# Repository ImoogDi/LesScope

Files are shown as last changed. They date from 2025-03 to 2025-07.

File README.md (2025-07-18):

# LesScope
Arduino based Dual Channel Scope for eurorack-modular synths.

**Table of Contents**

- [Introduction](#intro)
- [Construction Guide](./doc/constructionguide.md)
- [LesScope-Menu](#menu)
- [Technical data](#technical-data)
- [References](#references)
- [License](#license)

## Introduction

This eurorack-modul is designed for modular-synthesizers as dual channel scope modul.  
Only two active parts are required to sample the signal at the jack-inputs.  
 1. Arduino Nano V3.x.  
 2. Quad Op Amp MCP6004 rail-to-rail input/output.  

The Arduino Nano samples the amplified signal on two 10-Bit A/D multiplexed inputs.  
Sampled-data are then traced on the 1.3'' OLED display.  
Dataentry and menu-selections are possible with that encoder <u>Select</u>.  
AC/DC coupling is selectable for both channels on two switches.  
Every channel has two jacks linked together for signal-input and routing to other inputs.  
That signal on <u>Channel1</u> is normalized to the <u>Trigger</u> input-jack.  
With an additonal cable plugged into the <u>Trigger</u> jack a different trigger-signal can be used.  

All parts are common available and DIY-friendly designed.   
(Details see attached pictures)  

- Modul Frontpanel  
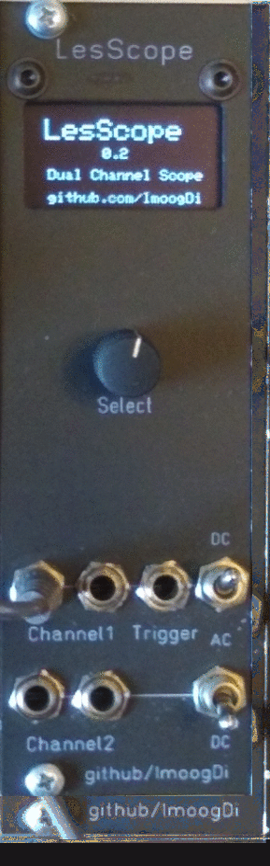
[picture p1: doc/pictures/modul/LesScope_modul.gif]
Modul: LesScope Front
 

- Modul Backside  
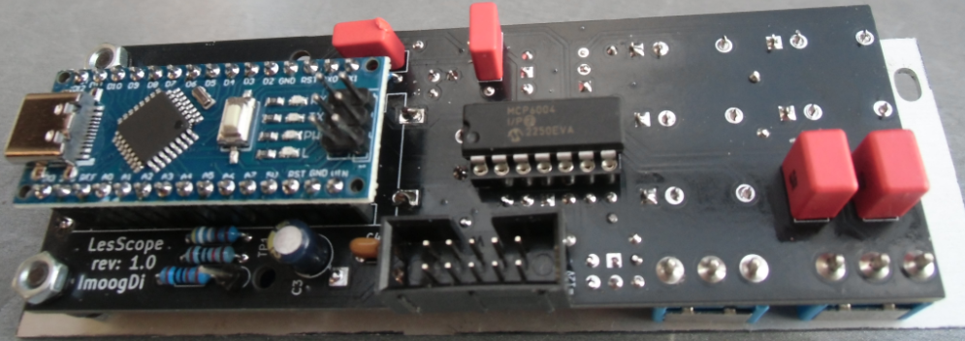
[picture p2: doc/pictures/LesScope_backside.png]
Modul: LesScope Backside
 

- Modul Right side  
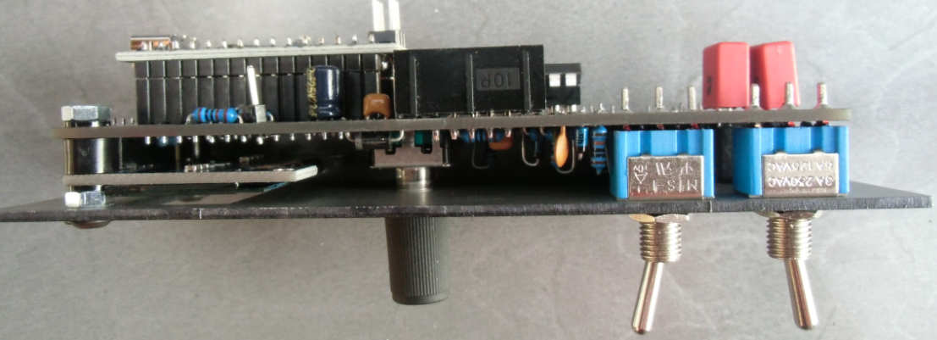
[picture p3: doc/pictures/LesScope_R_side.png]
Modul: LesScope Backside
 

- Modul Left side  
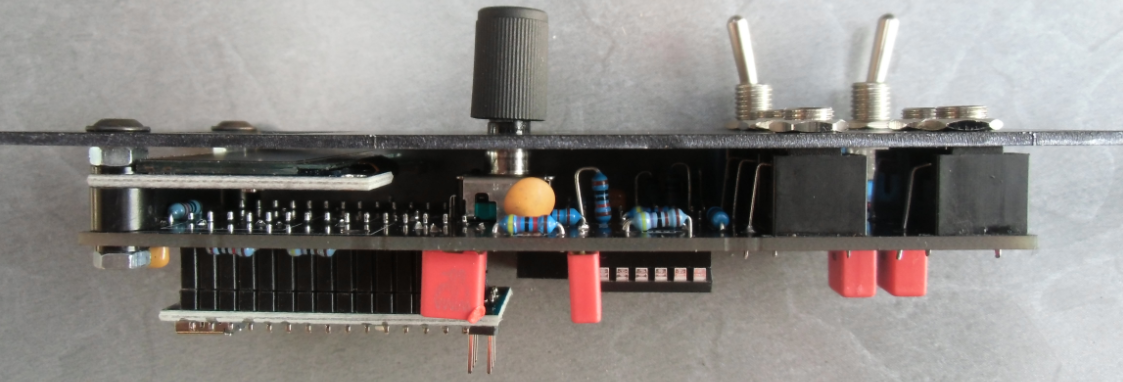
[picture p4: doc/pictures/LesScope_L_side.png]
Modul: LesScope Backside
 

- Dual Trace example  
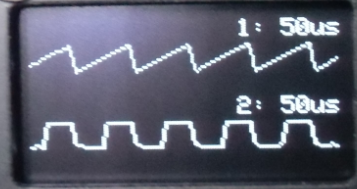
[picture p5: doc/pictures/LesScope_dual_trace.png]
Dual Trace example
 

## LesScope-Menu
- Menu example  
Menu example
 

## Technical data

- size:  
  height: 3VP (133,35mm)  
  width : 8HP ( 40,3mm)  
  depth : 35mm

- power:  
   +5Volt, 0 mA  
  +12Volt, 45mA  
  -12Volt, 0 mA  

- display:  
    128x64 pixel 1.3inch OLED with SPI interface  

- MCU:  
    Arduino Nano V3.x ATmega 328P  

- Electrical features:  
    Rotary encoder with push-button.  
    Two separate channels with AC/DC-coupling.  
    Input Voltage 10Vp-p for both channels.  
    Menu selectable signal-amplification (1...4:Channel1; 1...2:Channel2).  
    Sampling-rate range: 50us...100msec on both channels.  
    Separate trigger-input (default linked to <u>Channel1</u>).  

- Measurement-capabilities (only on <u>Channel1</u>):  
    Frequency-measurement range: ~10Hz...~6000Hz.  
    Tuning-check range: C0(16.35Hz)...C8(4186.01Hz).  

There are fife 3.5mm jacks available with following functions.  
<table>
<tr>
    <th>Jack-Name</th>
    <th>Function</th>
    <th>Comment</th>
</tr>
<tr>
    <td>Channel1 (two jacks)</td>
    <td>Signal input for <u>Channel1</u></td>
    <td>the two jacks are linked together and <br>this signal is normalized to <u>Trigger</u> input.</td>
</tr>
<tr>
    <td>Channel2 (two jacks)</td>
    <td>Signal input for <u>Channel2</u></td>
    <td>the two jacks are linked together.</td>
</tr>
<tr>
    <td>Trigger</td>
    <td>Signal input for <u>Trigger</u></td>
    <td>this signal is normalized to <u>Channel1</u>.</td>
</tr>
</table>

## References

* [mzuelch Display](https://github.com/mzuelch/CATs-Eurosynth/tree/main/Modules/HAGIWO/Display)
* [frequency measure](http://www.pjrc.com/teensy/td_libs_FreqMeasure.html)
* [encoder](http://www.pjrc.com/teensy/td_libs_Encoder.html)
* [Adafruit SH110X display-driver](https://github.com/adafruit/Adafruit_SH110X/actions)
* [midi conversion table](https://musicinformationretrieval.com/midi_conversion_table.html)

## License
> Hardware:cc by-nc-sa 4.0  ([details](https://creativecommons.org/licenses/by-nc-sa/4.0/))  
> Software:licensed under GPL-3.0 ([details](https://www.gnu.org/licenses/gpl-3.0.html.en))

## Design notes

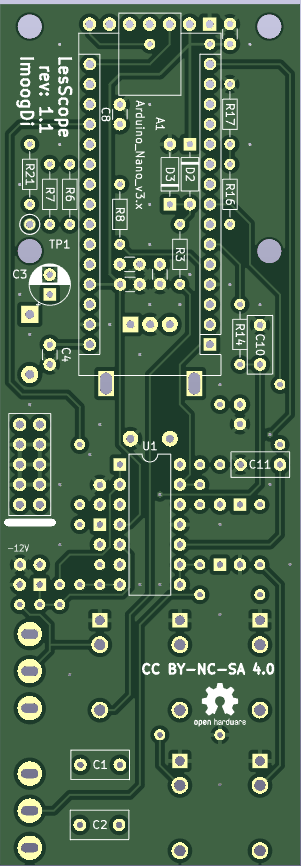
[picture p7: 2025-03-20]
doc/pictures/LesScope_Bot.png

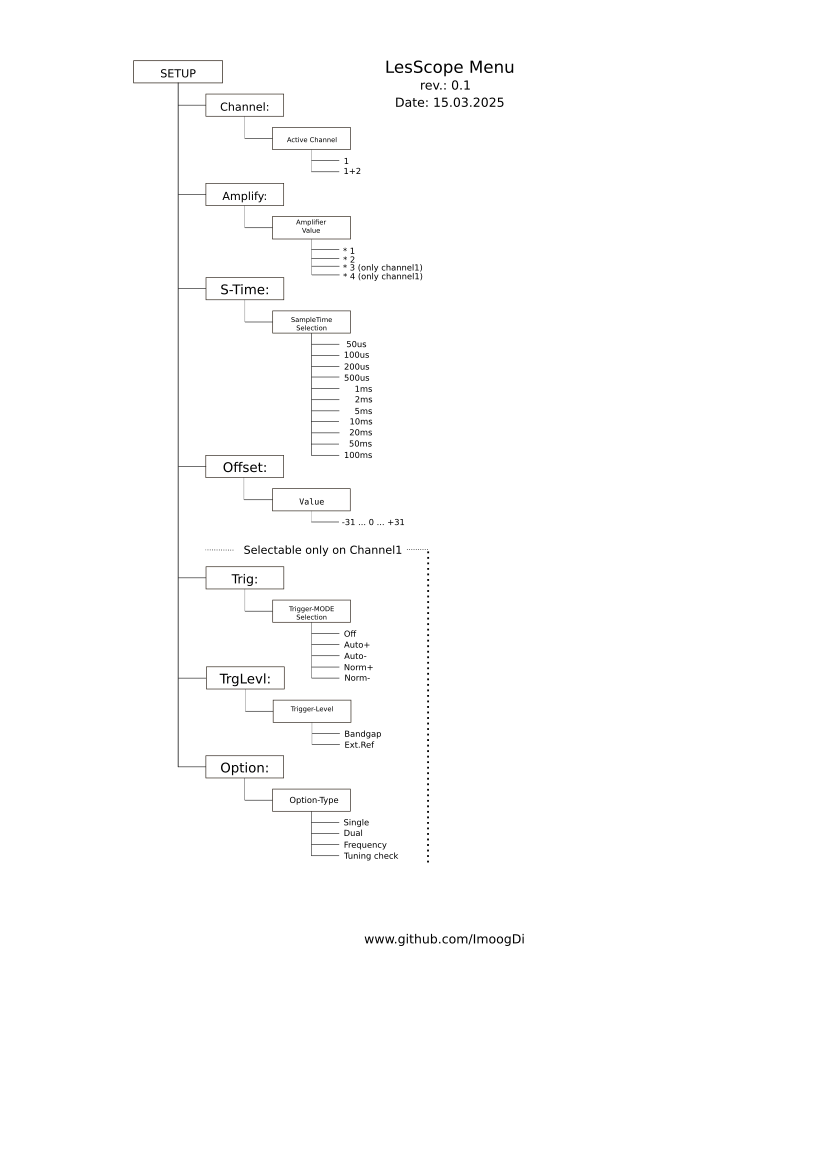
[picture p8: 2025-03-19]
doc/pictures/menu/LesScope_Menu_Struct.png

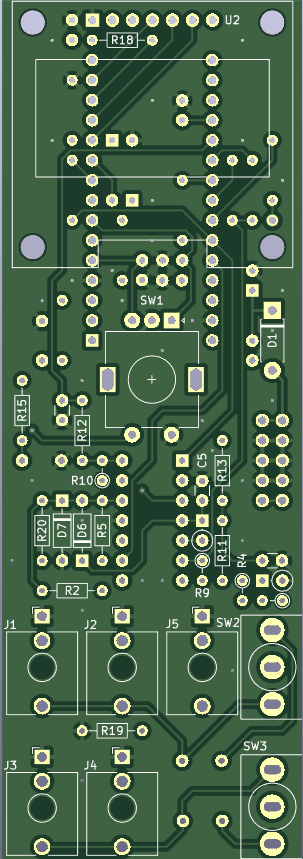
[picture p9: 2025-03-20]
doc/pictures/LesScope_Top.png

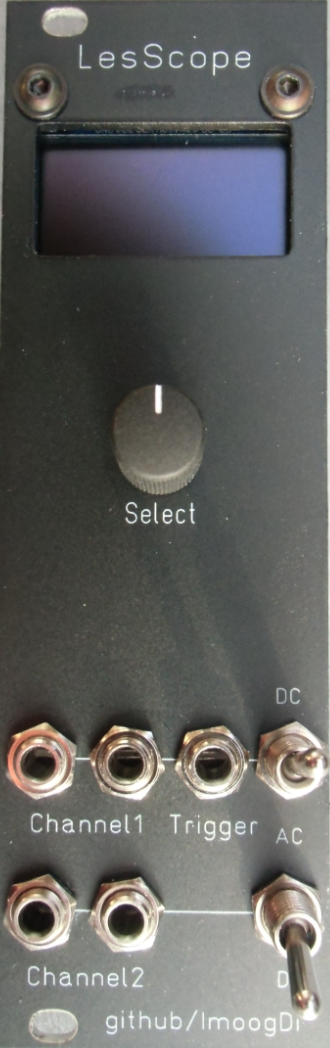
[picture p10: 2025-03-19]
doc/pictures/LesScope_front.png

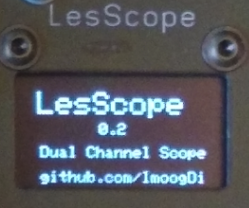
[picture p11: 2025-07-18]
doc/pictures/LesScope_startup.png

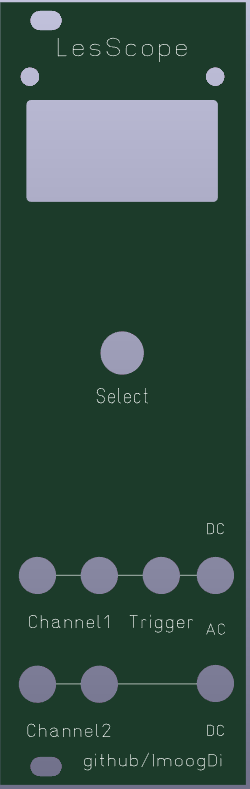
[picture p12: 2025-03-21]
hw/frontpanel/LesScope_frontpanel.png

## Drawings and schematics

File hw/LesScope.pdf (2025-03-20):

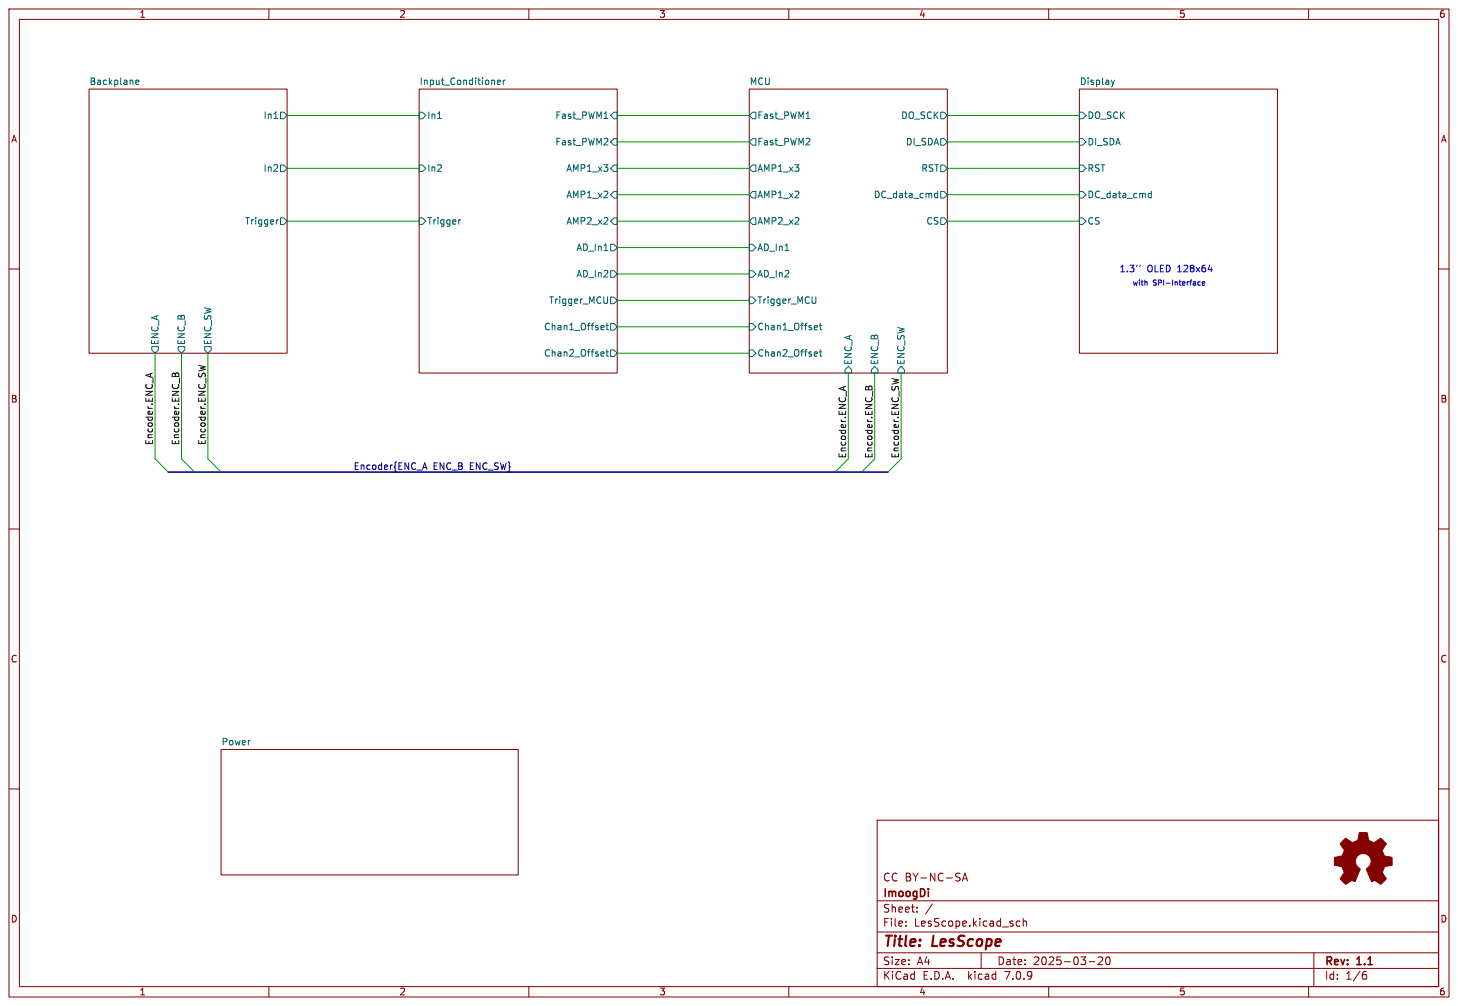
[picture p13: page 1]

ImoogDi CC BY-NC-SA

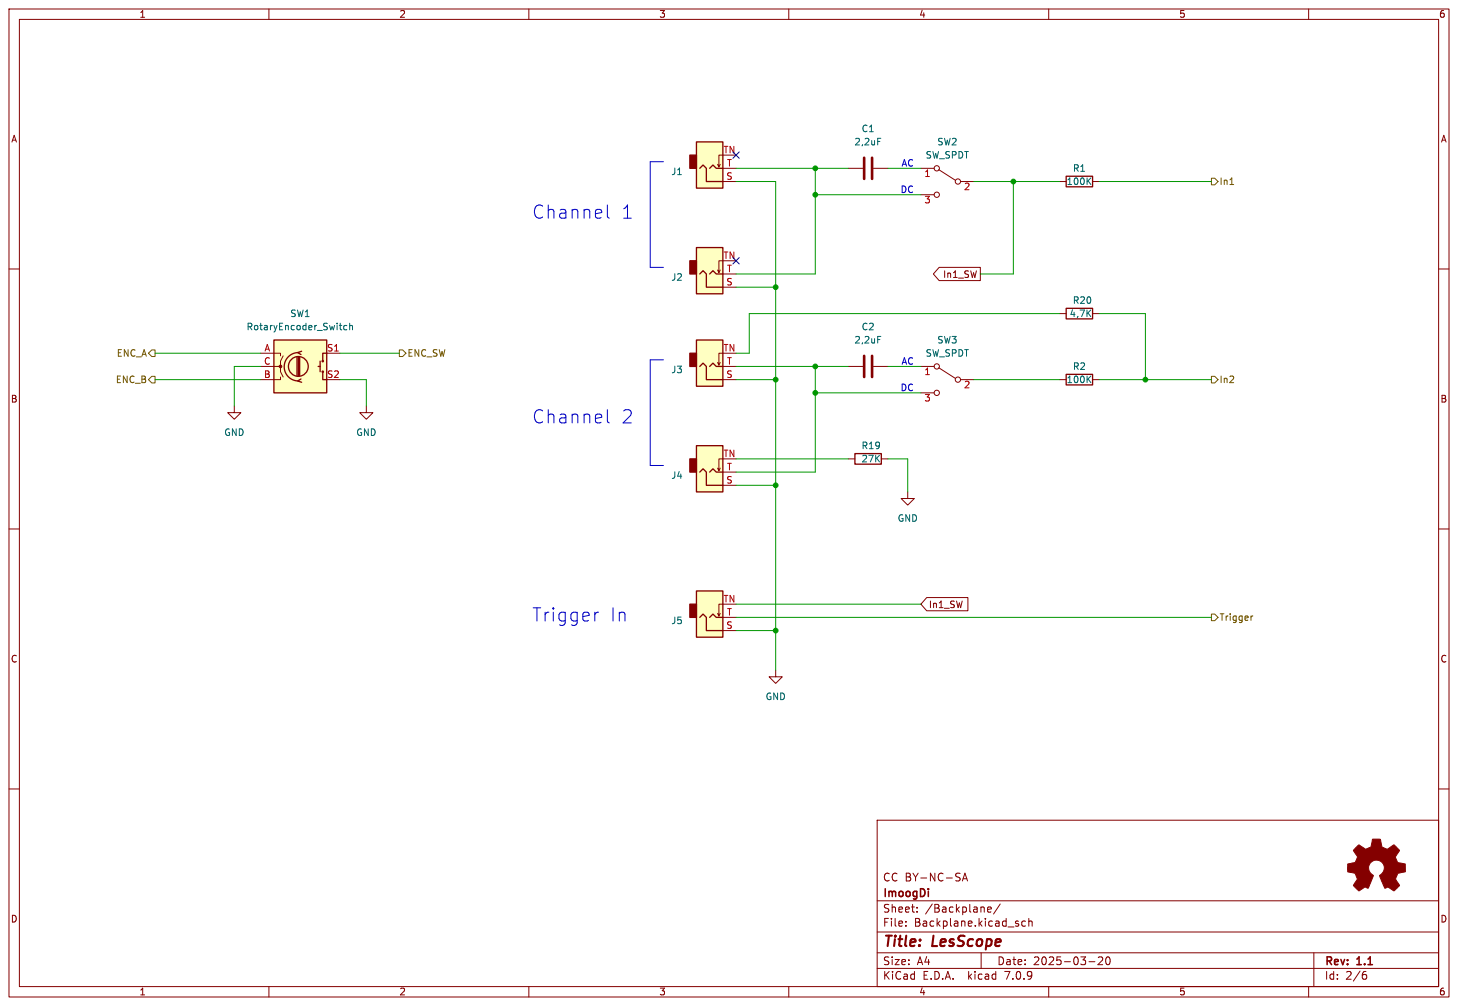
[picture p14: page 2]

ImoogDi CC BY-NC-SA

File: Backplane.kicad_sch Sheet: /Backplane/
Id: 2/6 Title: LesScope

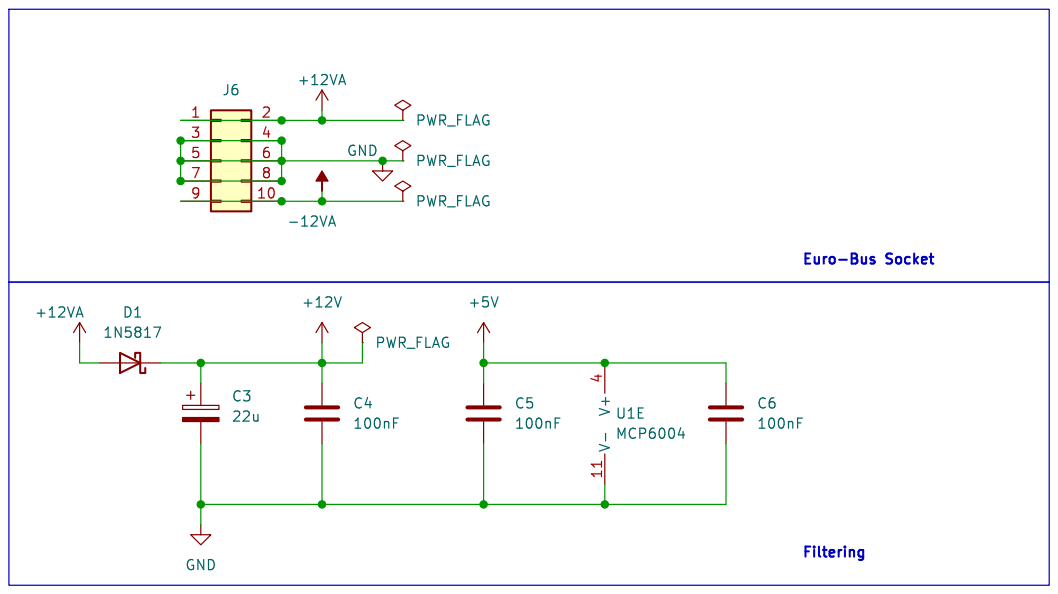
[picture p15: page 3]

4 U1E MCP6004 Euro-Bus Socket Filtering

ImoogDi CC BY-NC-SA

File: Power.kicad_sch Sheet: /Power/
Id: 3/6 Title: LesScope

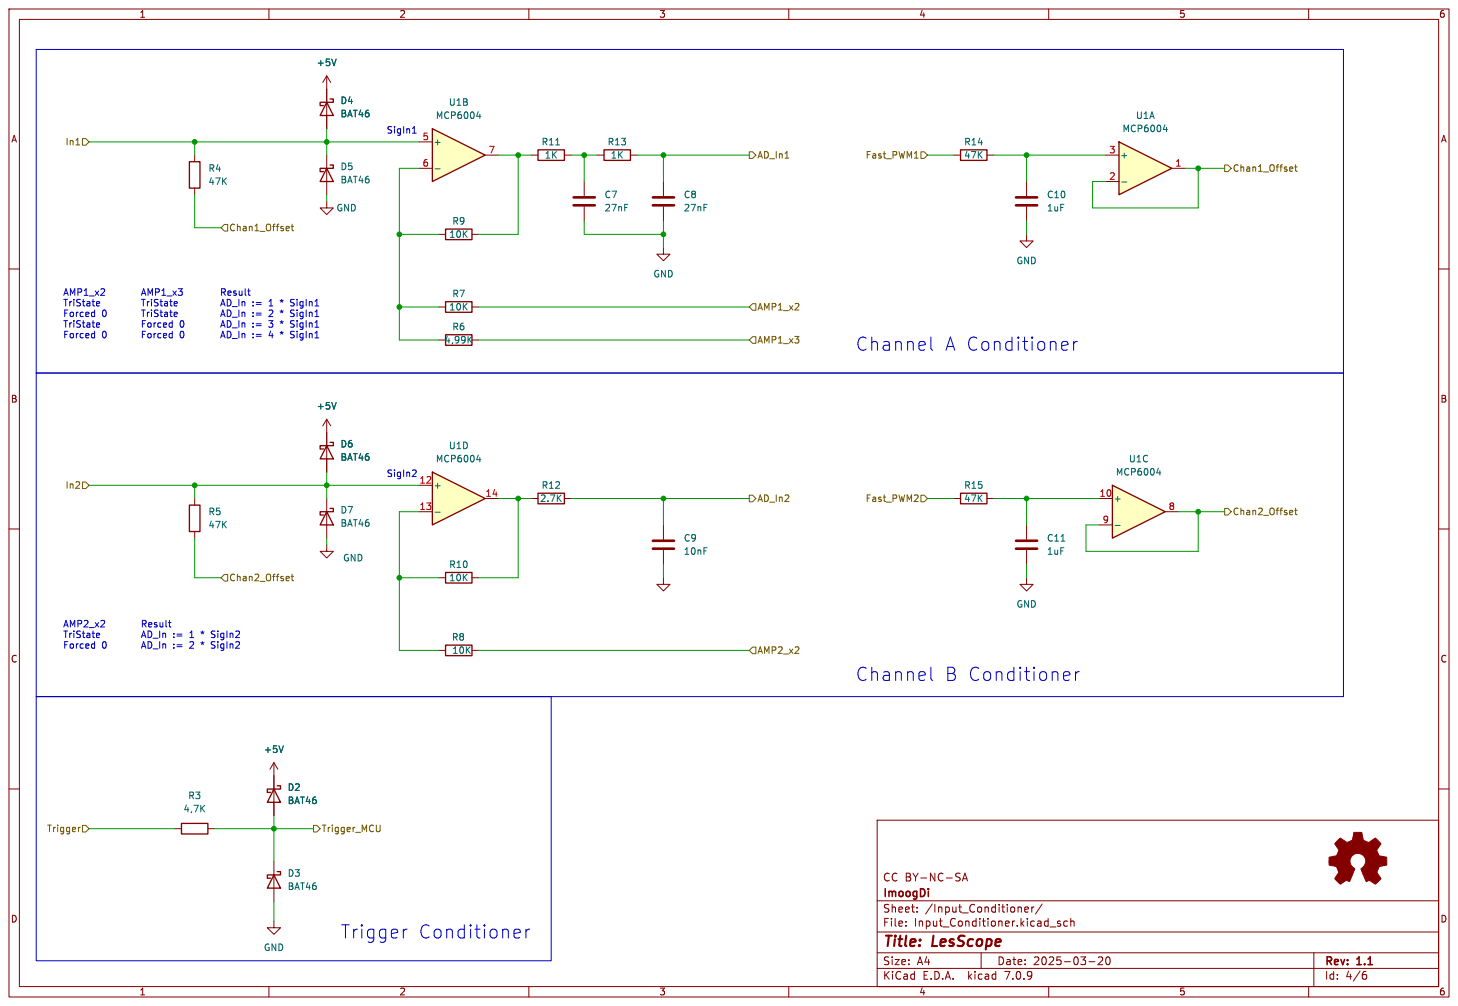
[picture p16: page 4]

ImoogDi CC BY-NC-SA

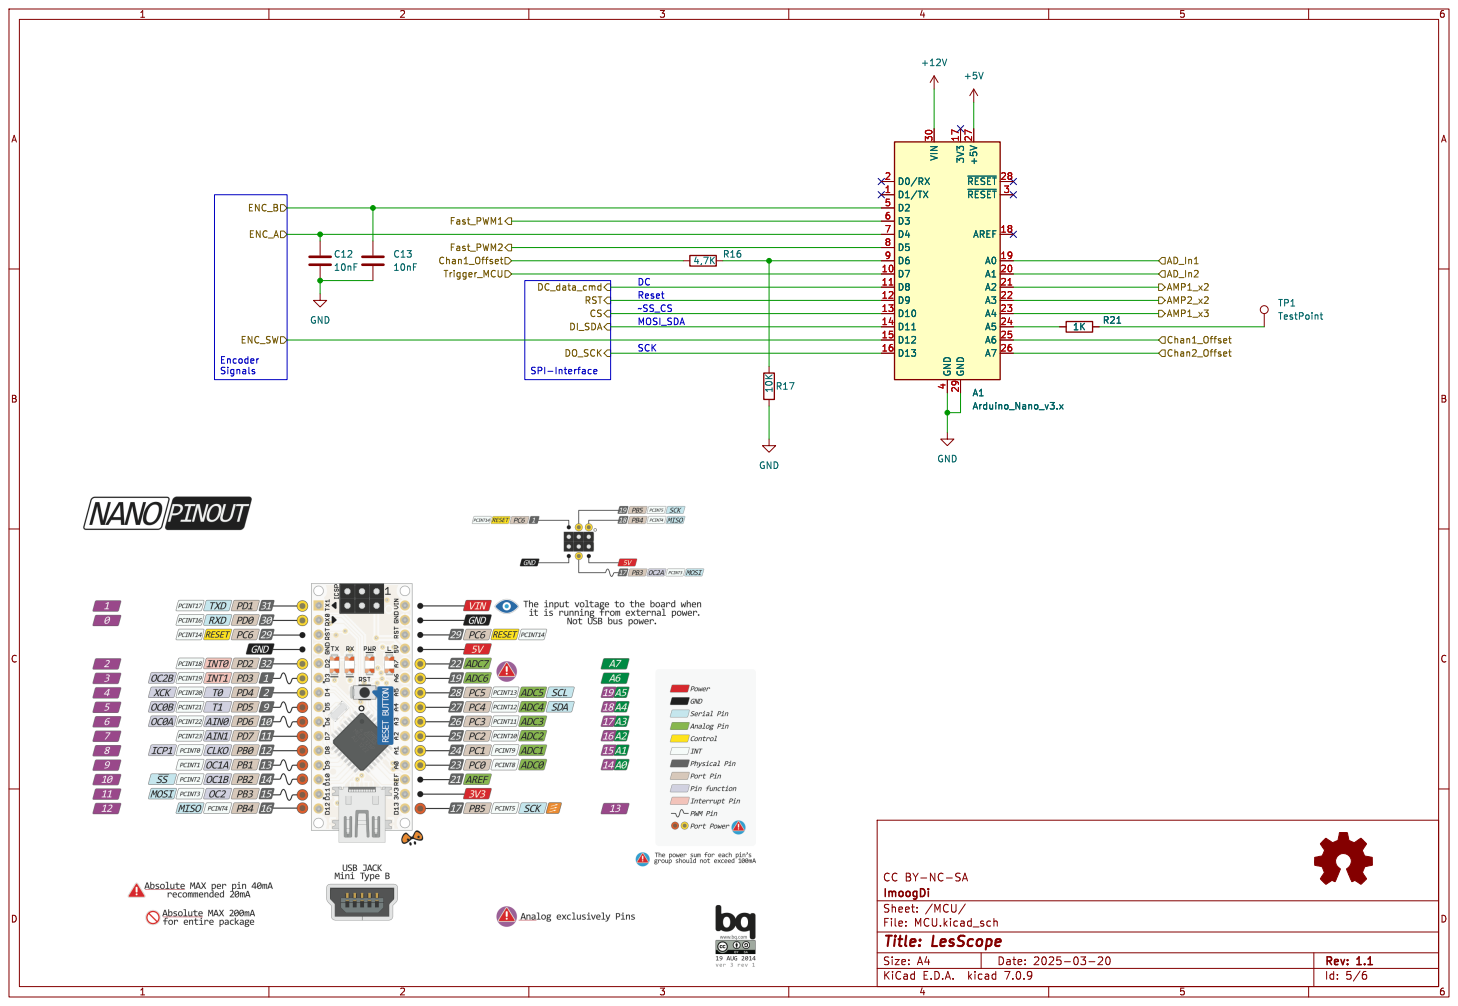
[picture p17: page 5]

ImoogDi CC BY-NC-SA

File: MCU.kicad_sch Sheet: /MCU/
Id: 5/6 Title: LesScope

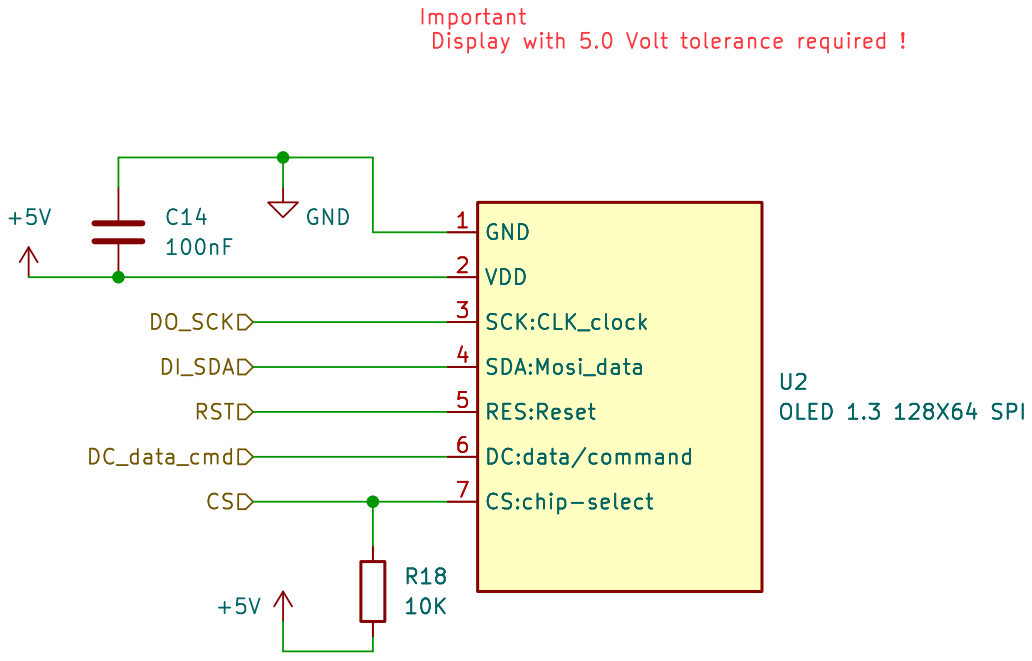
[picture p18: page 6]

ImoogDi CC BY-NC-SA

File: Display.kicad_sch Sheet: /Display/
Id: 6/6 Title: LesScope

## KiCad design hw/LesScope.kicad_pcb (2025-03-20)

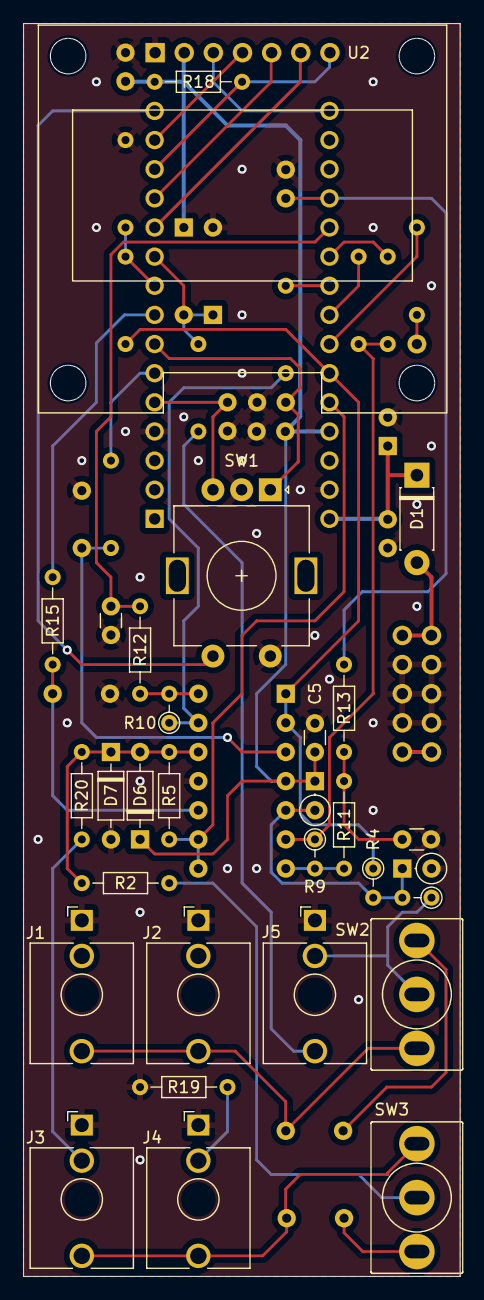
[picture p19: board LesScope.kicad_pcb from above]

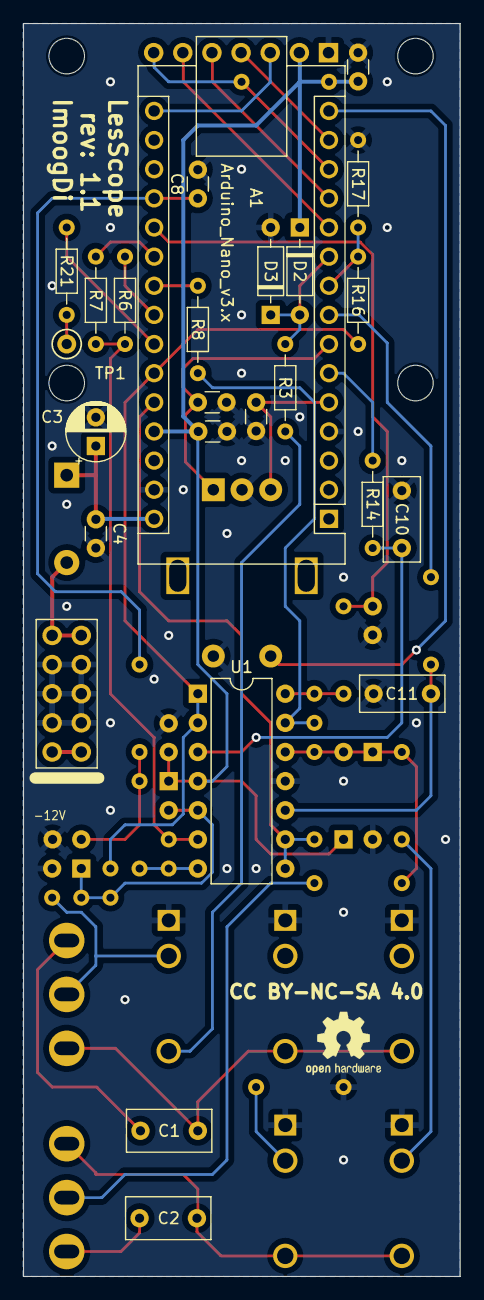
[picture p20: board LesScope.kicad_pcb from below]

Board: 2 copper layers, 38.1 x 109.2 mm, 56 parts (26 on the bottom side), 44 nets.

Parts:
A1: Arduino_Nano_v3.x; Arduino_Nano
C1, C2: 2,2uF; C_Rect_L7.2mm_W3.5mm_P5.00mm_FKS2_FKP2_MKS2_MKP2
C3: 22u; CP_Radial_D5.0mm_P2.50mm
C4, C5, C6, C14: 100nF; C_Disc_D3.0mm_W1.6mm_P2.50mm
C7, C8: 27nF; C_Disc_D3.0mm_W1.6mm_P2.50mm
C9, C12, C13: 10nF; C_Disc_D3.0mm_W1.6mm_P2.50mm
C10, C11: 1uF; C_Rect_L7.2mm_W3.0mm_P5.00mm_FKS2_FKP2_MKS2_MKP2
D1: 1N5817; D_DO-41_SOD81_P7.62mm_Horizontal
D2, D3, D6, D7: BAT46; D_DO-35_SOD27_P7.62mm_Horizontal
D4, D5: BAT46; D_DO-35_SOD27_P2.54mm_Vertical_KathodeUp
J1, J2, J3, J4, J5: AudioJack2_SwitchT; Jack_3.5mm_QingPu_WQP-PJ398SM_Vertical_CircularHoles
J6: Conn_02x05_Odd_Even; Pins_2x05_2.54mm_TH_Europower
R1: 100K; R_Axial_DIN0204_L3.6mm_D1.6mm_P2.54mm_Vertical
R2: 100K; R_Axial_DIN0204_L3.6mm_D1.6mm_P7.62mm_Horizontal
R3, R16, R20: 4,7K; R_Axial_DIN0204_L3.6mm_D1.6mm_P7.62mm_Horizontal
R4: 47K; R_Axial_DIN0204_L3.6mm_D1.6mm_P2.54mm_Vertical
R5, R14, R15: 47K; R_Axial_DIN0204_L3.6mm_D1.6mm_P7.62mm_Horizontal
R6: 4,99K; R_Axial_DIN0204_L3.6mm_D1.6mm_P7.62mm_Horizontal
R7, R8, R17, R18: 10K; R_Axial_DIN0204_L3.6mm_D1.6mm_P7.62mm_Horizontal
R9, R10: 10K; R_Axial_DIN0204_L3.6mm_D1.6mm_P2.54mm_Vertical
R11, R13, R21: 1K; R_Axial_DIN0204_L3.6mm_D1.6mm_P7.62mm_Horizontal
R12: 2.7K; R_Axial_DIN0204_L3.6mm_D1.6mm_P7.62mm_Horizontal
R19: 27K; R_Axial_DIN0204_L3.6mm_D1.6mm_P7.62mm_Horizontal
REF_A: OSHW-Logo2_7.3x6mm_SilkScreen
SW1: RotaryEncoder_Switch; RotaryEncoder_Alps_EC11E-Switch_Vertical_H20mm
SW2, SW3: SW_SPDT; Switch_Toggle_SPDT_Mini_SolderLug
TP1: TestPoint; TestPoint_WireHole
U1: MCP6004; DIP-14_W7.62mm
U2: OLED 1.3 128X64 SPI; DisplayModule_DM_OLED13

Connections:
+5V: A1.27 (+5V), C5.1, C6.1, C14.2, D2.1 (K), D4.1 (K), D6.1 (K), R18.1, U1.4 (V+), U2.2 (VDD)
+12V: A1.30 (VIN), C3.1, C4.1, D1.1 (K)
+12VA: D1.2 (A), J6.1, J6.2
-12VA: J6.9, J6.10
/Backplane/In1: D4.2 (A), D5.1 (K), R1.2, R4.2, U1.5 (+)
/Backplane/In2: D6.2 (A), D7.1 (K), R2.2, R5.2, R20.2, U1.12 (+)
/Backplane/Trigger: J5.T, R3.1
/Display/CS: A1.13 (D10), R18.2, U2.7 (CS:chip-select)
/Display/DC_data_cmd: A1.11 (D8), U2.6 (DC:data/command)
/Display/DI_SDA: A1.14 (D11), U2.4 (SDA:Mosi_data)
/Display/DO_SCK: A1.16 (D13), U2.3 (SCK:CLK_clock)
/Display/RST: A1.12 (D9), U2.5 (RES:Reset)
/Encoder.ENC_A: A1.7 (D4), C12.1, SW1.A
/Encoder.ENC_B: A1.5 (D2), C13.1, SW1.B
/Encoder.ENC_SW: A1.15 (D12), SW1.S1
/Input_Conditioner/AD_In1: A1.19 (A0), C8.1, R13.2
/Input_Conditioner/AD_In2: A1.20 (A1), C9.1, R12.2
/Input_Conditioner/AMP1_x2: A1.21 (A2), R7.2
/Input_Conditioner/AMP1_x3: A1.23 (A4), R6.2
/Input_Conditioner/AMP2_x2: A1.22 (A3), R8.2
/Input_Conditioner/Chan1_Offset: A1.25 (A6), R4.1, R16.1, U1.1, U1.2 (-)
/Input_Conditioner/Chan2_Offset: A1.26 (A7), R5.1, U1.8, U1.9 (-)
/Input_Conditioner/Fast_PWM1: A1.6 (D3), R14.1
/Input_Conditioner/Fast_PWM2: A1.8 (D5), R15.1
/Input_Conditioner/Trigger_MCU: A1.10 (D7), D2.2 (A), D3.1 (K), R3.2
GND: A1.4 (GND), A1.29 (GND), C3.2, C4.2, C5.2, C6.2, C7.2, C8.2, C9.2, C10.2, C11.2, C12.2, C13.2, C14.1, D3.2 (A), D5.2 (A), D7.2 (A), J1.S, J2.S, J3.S, J4.S, J5.S, J6.3, J6.4, J6.5, J6.6, J6.7, J6.8, R17.1, R19.2, SW1.C, SW1.S2, U1.11 (V-), U2.1 (GND)
In1_SW: J5.TN, R1.1, SW2.2 (B)
unnamed: A1.24 (A5), R21.1
unnamed: A1.9 (D6), R16.2, R17.2
unnamed: C7.1, R11.2, R13.1
unnamed: J3.TN, R20.1
unnamed: J4.TN, R19.1
unnamed: R10.2, R12.1, U1.14
unnamed: R9.2, R11.1, U1.7
unnamed: R21.2, TP1.1
unnamed: C1.1, SW2.1 (A)
unnamed: C1.2, J1.T, J2.T, SW2.3 (C)
unnamed: C2.1, SW3.1 (A)
unnamed: R2.1, SW3.2 (B)
unnamed: C2.2, J3.T, J4.T, SW3.3 (C)
unnamed: C10.1, R14.2, U1.3 (+)
unnamed: R6.1, R7.1, R9.1, U1.6 (-)
unnamed: C11.1, R15.2, U1.10 (+)
unnamed: R8.1, R10.1, U1.13 (-)

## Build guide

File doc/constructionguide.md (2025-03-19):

#  LesScope
 Construction of LesScope Dual Channel Scope eurorack-modul.

**Table of Contents**

- [Preconditions](#preconditions)
- [Construction](#construction)
- [First Switchon](#firstswitchon)
- [License](#license)

## Preconditions

- The PCB-Board must be available.  
- All BOM-parts must be available for the PCB-Board (see BOM-file: [LesScope](./../hw/bom/LesScope.html)).
- The frontpanel is required for aligned soldering the encoder and all jacks and switches to the PCB-Board.

## Construction

### PCB-Board: LesScope 'Backplane'

>#### 'Backplane' back side MTH-parts (start soldering here) [back side parts](./pictures/LesScope_Bot.png)

> start soldering MTH-parts on back side of the Board.  

>- place all resistors to the back side and solder them on top side.
>- place all capacitors to the back side and solder them on top side.
>- Watch the rigth orientation on capacitor C3.
>- fit the two 15-position, 1 row pin-sockets to the back side and solder them at the top side.  
>- fit the 5-position, 2 rows pin-header J6 (eurorack power) to the back side. Watch the rigth orientation and solder it on top side.  
>- place one DIP14 socket at U1-position on back side. Watch the rigth orientation and solder it on top side.  

>#### 'Backplane' top side MTH-parts [top side parts](./pictures/LesScope_Top.png)

> continue soldering MTH-parts on top side of the Board.  

>- place all resistors to the top side and solder them on back side. Be aware some of them mounted vertically.  
>- place all capacitors to the top side and solder them on back side.  
>- place all diodes to the top side. Watch the rigth orientation and solder them on back side. Be aware some of them mounted vertically.  
>- fit one 7-position, 1 row pin-header (for U2 OLED) to the back side and solder it at the top side.  
>- the currently mounted 'LesScope'-backplane top side should look like: [LesScope backplane top side (rev.: 1.1)](./pictures/Backplane_top_parts_mounted.png) 

>- **All following parts have to be aligned to the frontpanel and not yet soldered **
>- fit that snapin-encoder SW1 on PCB top side.
>- fit that switches SW2 and SW3 on PCB top side. Must be ON-ON type with two positions.
>- fit all fife jacks on PCB top side.
>- place the **frontpanel** on top side parts and **align** them.
>- check alignment and distance to the frontpanel, see: [alignment](./pictures/LesScope_R_side.png)
>- use nuts for the jacks and switches to fix that frontpanel to the PCB-parts.
>- now solder all parts on back side and make sure everything is still aligned.
>- unmount that frontpanel from backplane again.
>- mount that 1.3'' OLED display with one 7-position, 1 row pin-socket to the U2 pin-header on backplane. Cut that sockets a bit to get the right distance to the frontpanel.
>- use two 5mm spacer with 3mm screws and plastic washer to fix that display on the backplane, see [mounted parts](./pictures/LesScope_L_side.png).
>- remount that frontpanel to the backplane again and use nuts for jacks and switches to fix it.

## First Switchon
 Preconditions:

- Push IC U1 (MCP6004) into the DIP-socket on the Backplane (watch the alignment of Pin1).
- Push IC A1 (Arduino Nano V3.x) into the pin-sockets on the Backplane (watch the alignment of Pin1).
- The frontpanel and all PCB-parts are mounted.
- connect one 10pin buscabel between eurorack-bus and the LesScope Backplane (watch the alignment of Pin1 := -12V).

 Action: Optical check

- Switch **on** the eurorack-case power.
- Watch the startup-display at the frontpanel, example see:  
  [startup-display](./pictures/LesScope_startup.png)

 Action: Measurements

- Switch **on** the eurorack-case power.
- Measure voltages at points:  

<table>
<tr>
    <th>LesScope Board</th>
    <th>measuring point</th>
    <th>measured voltages</th>
</tr>
<tr>
    <td>A1 Arduino Nano (back side)</td>
    <td>IC A1 Pin30</td>
    <td>+12 Volt</td>
</tr>
<tr>
    <td>A1 Arduino Nano (back side)</td>
    <td>IC A1 Pin27</td>
    <td>+5 Volt</td>
</tr>
<tr>
    <td>U1 MCP6004 (back side)</td>
    <td>IC U1 Pin4</td>
    <td>+5 Volt</td>
</tr>
</table>

 Result:

If any measurement is out of range check the board and repeat the required steps.

 Postconditions:

None

## License
> Hardware:cc by-nc-sa 4.0  
> Software:licensed under GPL-3.0

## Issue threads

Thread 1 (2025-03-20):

possible to share the cad files?

KeLaiFu, 2025-03-20:
I have been looking at a number of your modules and considering attempting to build them, especially the new scope you just added.
I would like to be able to re-arrange them a little, and maybe make them into 1u versions etc, so would it be possible to upload the CAD (eagle/kicad etc) to the repo so I could easily do that?

Many thanks for sharing these awesome projects!

ImoogDi, 2025-03-20:
> ... so would it be possible to upload the CAD (eagle/kicad etc) to the repo so I could easily do that?

Yes, I'm working on it to finish this.
There are some open issues in the software, but the hardware runs stable.

Closed 2025-04-24.

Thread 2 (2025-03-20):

random pixels on right display corner

ImoogDi, 2025-03-20:
**Describe the bug**
there are random pixels on the right display-corner.

**To Reproduce**
Steps to reproduce the behavior:
some menu selection with encoder or drawings show this pixels.

**Expected behavior**
display without random pixels.

**Additional context**
none.

ImoogDi, 2025-04-24:
The random pixels are visible, if that frequency-measurement include-file is used.
File :  ./libraries/LScopeMenu.cpp
Line: 33  `#include <FreqMeasure.h>`

Reason is currently unknown.

Closed 2025-07-22.

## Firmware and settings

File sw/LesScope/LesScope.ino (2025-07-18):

/*
 * @file    LesScope.ino
 * @author  ImoogDi (https://github.com/ImoogDi/)
 * @brief   setup- and loop-part of project: LesScope.
 * @version 1.2
 * @date    2025-07-18
 * @copyright Copyright (c) 2025
 *
 *  This file is part of LesScope.
 *
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
 */
/*
 ****************************************************************************
 * LesScope is a Dual Channel Scope designed as eurorack-modul used
 *  in modular synthesizers.
 * Only the +12Volt/45mA from standard bus-connection is used.
 * This connection is diode-protected against misleading.
 *
 * Features:
 *  - Arduino Nano V3.X as dual-channel sampler and controller.
 *  - 1.3inch OLED display with SPI interface.
 *  - rotary encoder with push-button for data-selection and -change.
 *  - standard patchcabel can be used on input-jacks.
 *  - Any input is interconnected to a second jack per channel.
 *  - AC/DC coupling selectable for both channels on two switches.
 *  - extra input for Trigger-signal (normalized with Channel1-signal).
 *
 ****************************************************************************
 * Rotaryencoder/Button:
 *  encoder turn  left/right: menu activating, selection and changing data.
 *  button short  press     : mark and store selected data.
 *  button double press     : back to previous menu (only if menu is active).
 *  button long   press     : saving configuration-data to EEPROM.
 *
 * The signal-draw is automatic active again after 5 seconds without any
 *  encoder and/or button action.
 ****************************************************************************
 * Required libraries:
 *  - Frequency measure: http://www.pjrc.com/teensy/td_libs_FreqMeasure.html
 *  - Encoder          : http://www.pjrc.com/teensy/td_libs_Encoder.html
 *
 * Further infos and links:
 *  - mzuelch Display  :
 *      https://github.com/mzuelch/CATs-Eurosynth/tree/main/Modules/HAGIWO/Display
 *
 ****************************************************************************
 */

#include "LScopeCfg.h"
#include "LScopeMenu.h"
#include "LScopeSample.h"
#include "LScopeSetHW.h"

CMenu LSMenu(SCREEN_WIDTH, SCREEN_HEIGHT, &SPI, OLED_SPI_DC,
                        OLED_SPI_RESET, OLED_SPI_CS);

void setup() {
  //serial deactivated, needs ca. 1kByte Flash and 100Byte ram.
//  Serial.begin(9600);

  //hardware init
  hw_init();

  //display setting
  LSMenu.begin(0, true);
  // uncomment //#define SH110X_NO_SPLASH
  //   in file:Adafruit_SH110X/Adafruit_SH110X.h
  // if no Adafruit-logo is wanted

  //init signal-sampling
  sample_init();
  LSMenu.updateMenu();
};

void loop() {
  CRotaryEncoder::Button_t bstate = LSMenu.rotaryencoder.getButtonState();

  LSMenu.CheckMenuTimeout();
  LSMenu.Drawupdate();

  if (LSMenu.rotaryencoder.update()) {
    LSMenu.updateSelection();
  }
  if (bstate != CRotaryEncoder::Open)
  {
    switch (bstate)
    {
      case CRotaryEncoder::HoldOn:
        LSMenu.SaveConfigdata();
        break;
      case CRotaryEncoder::Released:
        break;
      case CRotaryEncoder::Pushed:
        LSMenu.updateMenu();
        break;
      case CRotaryEncoder::DoubleClicked:
        LSMenu.SetPrevMenu();
        break;
    }
  }
};

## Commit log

2025-03-20 hw and sw added
    [Backplane.kicad_sch, Display.kicad_sch, Input_Conditioner.kicad_sch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]
2025-03-21 frontpanel added
    [LesScope_frontpanel.kicad_pcb]
2025-07-17 update for issues:#2 & #3
    [LesScope.ino]

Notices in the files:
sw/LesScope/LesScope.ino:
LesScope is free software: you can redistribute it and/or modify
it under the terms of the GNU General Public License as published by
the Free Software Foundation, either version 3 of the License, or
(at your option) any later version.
